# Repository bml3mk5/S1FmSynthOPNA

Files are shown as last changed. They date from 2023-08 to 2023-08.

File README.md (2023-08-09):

# FM音源カード for 日立 MB-S1 (OPNA (YM2608) バージョン)

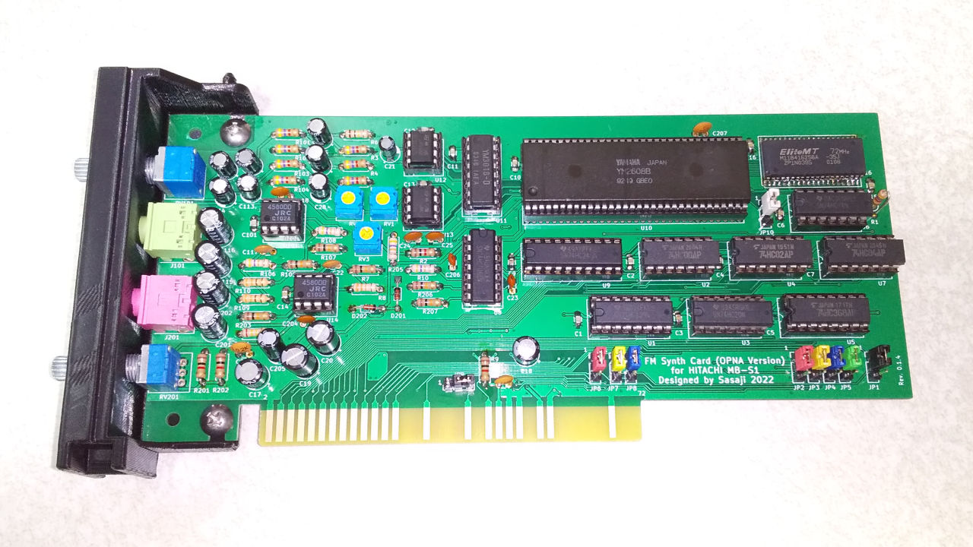
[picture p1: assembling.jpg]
Example of an assembling


## フォルダ構成

    BackCover/ ..................... 背面カバーの3Dモデル
    Board/ ......................... 基板設計(KiCAD 6.0)

-----
# FM Synthesis Card for HITACHI MB-S1 (OPNA (YM2608) Version)

## Folders:

    BackCover/ ..................... 3D models of the back cover
    Board/ ......................... The circuit board design (KiCAD 6.0)

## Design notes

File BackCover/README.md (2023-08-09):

# 背面カバーの3Dモデル

## ファイル構成

    S1BackSize_OPNA.FCStd .......... 本体の3Dデザイン(FreeCAD 0.2)
    S1BackSize_OPNA-Body.stl ....... 本体の3Dモデル
    S1BackSize_OPNA_Sp.FCStd ....... サポート部品の3Dデザイン(FreeCAD 0.2)
    S1BackSize_OPNA_Sp-Body001.stl . サポート部品の3Dモデル
    MegaZero2.0/ ................... Anycube MegaZero2.0用3Dデータ

-----
# 3D models of the back cover

## Files:

    S1BackSize_OPNA.FCStd .......... The 3D design of the main parts (FreeCAD 0.2)
    S1BackSize_OPNA-Body.stl ....... The 3D model of the main parts
    S1BackSize_OPNA_Sp.FCStd ....... The 3D design of the support parts for a 3D printer (FreeCAD 0.2)
    S1BackSize_OPNA_Sp-Body001.stl . The 3D model of the support parts for a 3D printer
    MegaZero2.0/ ................... The 3D data for Anycube MegaZero2.0

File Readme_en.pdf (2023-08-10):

## FM Synthesis Card （OPNA Version） for HITACHI MB-S1

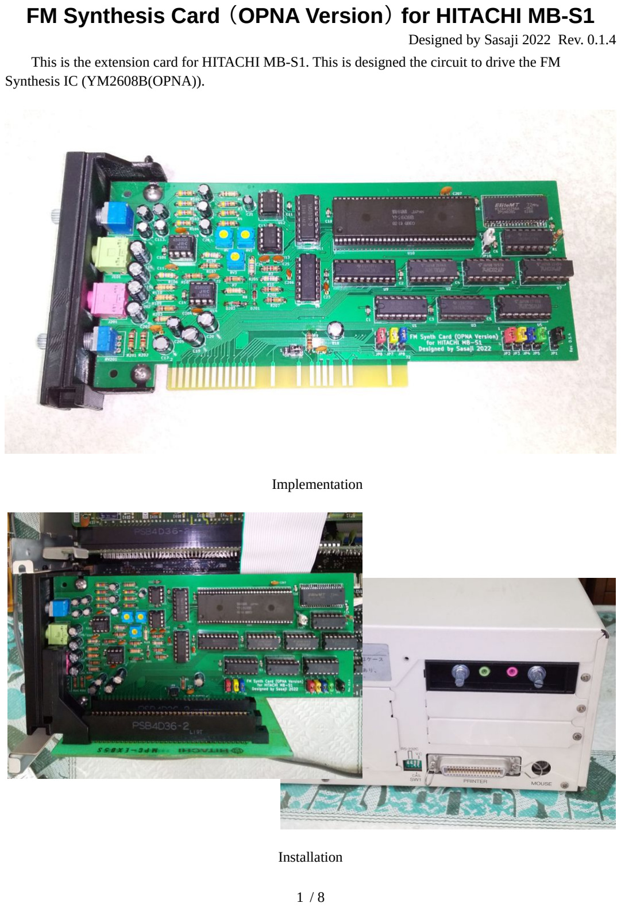
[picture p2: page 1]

Designed by Sasaji 2022 Rev. 0.1.4 This is the extension card for HITACHI MB-S1. This is designed the circuit to drive the FM Synthesis IC (YM2608B(OPNA)).

Implementation

Installation

## I/OPorts

The I/O ports are decided by Jumper setting. See detail Setting Jumper section.
| Jumper 1-2 | Jumper 2-3
YM2608B FM1ch~3ch, SSG, Rhythm | Address | $FFE7 | $FF1F
| Data | $FFE6 | $FF1E
YM2608B FM4ch~6ch, ADPCM | Address | $FFEF | $FF17
| Data | $FFEE | $FF16

## Setting Jumper

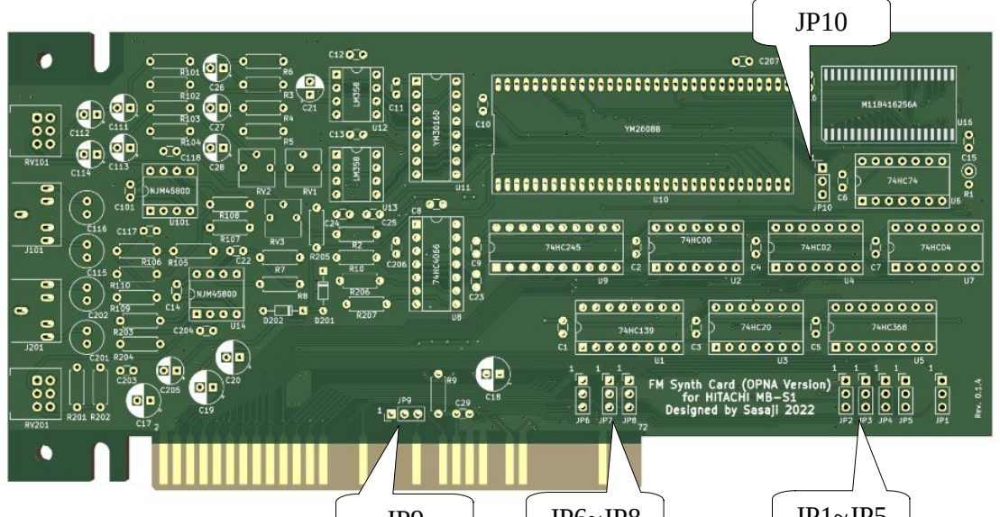
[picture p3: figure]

I/O Addresses of FM Synth (JP1～JP8)
- Pin number are #1,#2 and #3 from the top.
| JP1～JP6 | JP7, JP8 (*3)
I/O addresses Also use I/O addresses at $FF1E and $FF1F (*1) $FF16 and $FF17 to control FM4～6ch | Short 2-3 Short 2-3 | Short 2-3 Short 1-2
I/O addresses Also use I/O addresses at $FFE6 and $FFE7 (*2) $FFEE and $FFEF to control FM4～6ch | Short 1-2 Short 1-2 | Short 2-3 Short 1-2

(*1) Don’t use on B mode of MB-S1/30 and 40 because duplicate addresses of the FD interface. (*2) Select this if you use as Extended PSG.
(*3) The jumpers JP7 and JP8 must be at the same shorting position.
JP9 | JP6~JP8 | JP1~JP5

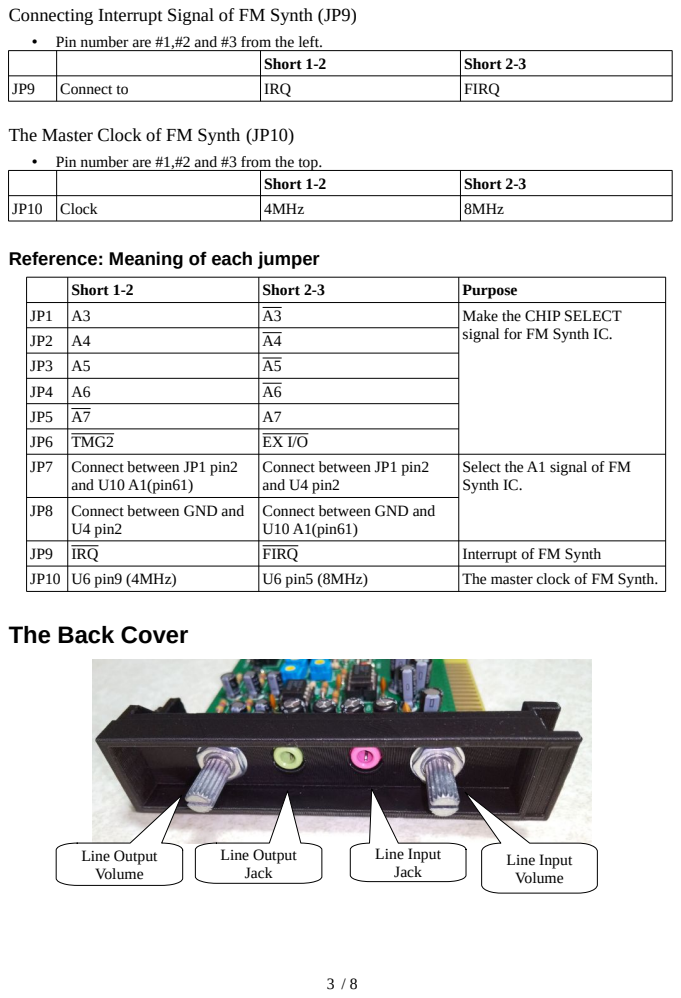
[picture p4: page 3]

Connecting Interrupt Signal of FM Synth (JP9)
• Pin number are #1,#2 and #3 from the left.

Short 1-2 | Short 2-3

JP9 | Connect to | IRQ | FIRQ

The Master Clock of FM Synth (JP10)
• Pin number are #1,#2 and #3 from the top.

JP10 | Clock | 4MHz | 8MHz

Reference: Meaning of each jumper

Short 1-2 | Short 2-3 | Purpose
JP1 | A3 | A3 | Make the CHIP SELECT
A4 | A4 | signal for FM Synth IC. JP2
JP3 | A5 | A5
JP4 | A6 | A6
JP5 | A7 | A7
JP6 | TMG2 | EX I/O
JP7 | Connect between JP1 pin2 and U10 A1(pin61) | Connect between JP1 pin2 and U4 pin2 | Select the A1 signal of FM Synth IC.

JP8 | Connect between GND and U4 pin2 | Connect between GND and U10 A1(pin61)

JP9 | IRQ | FIRQ | Interrupt of FM Synth
JP10 | U6 pin9 (4MHz) | U6 pin5 (8MHz) | The master clock of FM Synth.

## Setting Volume

## Balance of FM and SSG

Adjust RV1 - RV3 on the board. RV1: Left sound on FM
RV2: Right sound on FM
RV3:SSG

Usual position is 50 – 70%.

- When adjusted the RV1 - RV3, the volume of the built-in speaker and line out also changes.

## The volume of line output

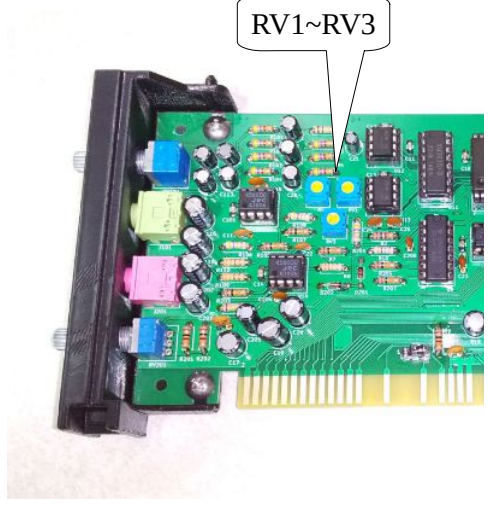
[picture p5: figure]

Adjust the volume appropriately according to the connected device.
- Small headphones (earphones): about 50%
- Line input of another device: about 20%
When using a large speaker, it is necessary to connect it via a drive circuit (amplifier).
- The PSG sound and BEEP on the main unit are not output from this terminal.

## The volume of line input

Adjust the volume appropriately according to the connected device.
- Line output of another device: about 20%
- Headphone output of another device: about 50%
When using a mic for PC, it is necessary to connect it via a drive circuit (amplifier).
- During recording, the audio from the main unit and line out are muted. And a little noise is recorded.

## Installing

Need the extension board (Riser card) to install to the main unit.
Parts Number：MPC-EX01S(MB-S1/10,20), MPC-EX03S, MPC-EX05S(MB-S1/30,40)

## Attention

This board cannot installs on LimeLight.
This board is a prototype. No consideration is given to noise generated during use and deterioration over time.

## Parts List

Parts number #1 to #99 are mandatory.
Parts number #101 to #199 are used on the line output circuit.
Parts number #201 to #299 are used on the line input circuit.
Parts Number | Parts Name | Qty. | Description
C1~C16, C101 | Ceramic Capacitor | 17 | 0.1uF, 10V～ | Power, Bypass
C22, C117, C118, C204 | Ceramic Capacitor | 4 | 100pF, 16V～ | Analog
C23, C206 | Ceramic Capacitor | 2 | 47pF, 10V～ | Analog
C24, C25, C207 | Ceramic Capacitor | 3 | 2200pF, 10V～ | Analog
C29, C203 | Ceramic Capacitor | 2 | 1000pF, 16V～ | Analog
C17, C18 | Electrolytic Capacitor | 2 | 47uF, 16V～ | Power, Bypass
C19, C20 | Electrolytic Capacitor | 2 | 100uF, 25V～ | Power, Bypass
C21 | Electrolytic Capacitor | 1 | 10uF, 16V～ | Analog
C26~C28, C111~C114 | Electrolytic Capacitor | 7 | 22uF, 16V～ | Analog
C205 | Electrolytic Capacitor | 1 | 22uF, 25V～ | Analog
C115, C116, C201, C202 | Electrolytic Capacitor (No polarity) | 4 | 22uF, 16V～ | Analog
R1 | Carbon Registor | 1 | 4.7KΩ, 1/4W～ | Digital, Pullup
R2, R9, R201, R202 | Carbon Registor | 4 | 1KΩ, 1/4W～ | Analog
R3~R5, R101~R104 | Carbon Registor | 7 | 4.7KΩ, 1/4W～ | Analog
R6 | Carbon Registor | 1 | 100KΩ, 1/4W～ | Analog
R7, R105, R107, R203, R206, R207 | Carbon Registor | 6 | 10KΩ, 1/4W～ | Analog
R8 | Carbon Registor | 1 | 33KΩ, 1/4W～ | Analog
R10, R106, R108, R205 | Carbon Registor | 4 | 47KΩ, 1/4W～ | Analog
R109, R110 | Carbon Registor | 2 | 330Ω, 1/4W～ | Analog
R204 | Carbon Registor | 1 | 240KΩ, 1/4W～ | Analog

RV1~RV3 | Potentiometer | 3 | 10KΩ (Tokyo Cosmos GF063P etc.) | Analog
RV101 | Potentiometer | 1 | 10KΩ, 2 Interlocking (Alps RK079 etc.) | Analog
RV201 | Potentiometer | 1 | 10KΩ, 1 or 2 Interlocking (Alps RK079 etc.) | Analog
D201, D202 | Diode | 2 | 1N4148 | Analog
U1 | CMOS Logic IC | 1 | 74HC139, DIP16 | Digital
U2 | CMOS Logic IC | 1 | 74HC00, DIP14 | Digital
U3 | CMOS Logic IC | 1 | 74HC20, DIP14 | Digital
U4 | CMOS Logic IC | 1 | 74HC02, DIP14 | Digital
U5 | CMOS Logic IC | 1 | 74HC368, DIP16 | Digital
U6 | CMOS Logic IC | 1 | 74HC74, DIP14 | Digital
U7 | CMOS Logic IC | 1 | 74HC04, DIP14 | Digital
U8 | CMOS Logic IC | 1 | 74HC4066, DIP14 | Digital
U9 | CMOS Logic IC | 1 | 74HC245, DIP20 | Digital
U10 | FM Synth IC | 1 | YM2608B, shrink DIP64 | Digital and Analog
U11 | DAC | 1 | YM3016D, DIP16 | Analog
U12, U13 | Opamp | 2 | LM358, DIP8 (+5V) | Analog
U14, U101 | Opamp | 2 | NJM4580DD, DIP8 (±12V) | Analog
U16 | DRAM | 1 | M11B416256A, SOIC40 | Digital
J101, J201 | Audio Jack | 2 | Stereo (PJ-317) | Analog
JP1~JP10 | Jumper | 10 | Pin Header 3pin x1 2.54mm pitch straight
| Jumper pin | 10 | To short pin headers.

Options

Parts Number | Parts Name | Qty. | Description
| IC Socket | 4 | DIP8
| IC Socket | 6 | DIP14
| IC Socket | 3 | DIP16
| IC Socket | 1 | DIP20
| IC Socket | 1 | Shrink DIP64

## Attention to build the board

Secure the back cover and board with two truss pin screws (B type, grooved) M3.5 x 8mm.
The back cover is fragile, so be careful and do not use too much force when tightening the screws.

## When omitting the line output circuit

No need for #100 series parts.

## When omitting the line input circuit

No need for #200 series parts.
Connect pin2 and pin3 of U14 to pin4 (GND).
U8 (74HC4066) can be omitted. If omitted:
- Connect pin3 and pin4 on U8.
- Also need not R10.

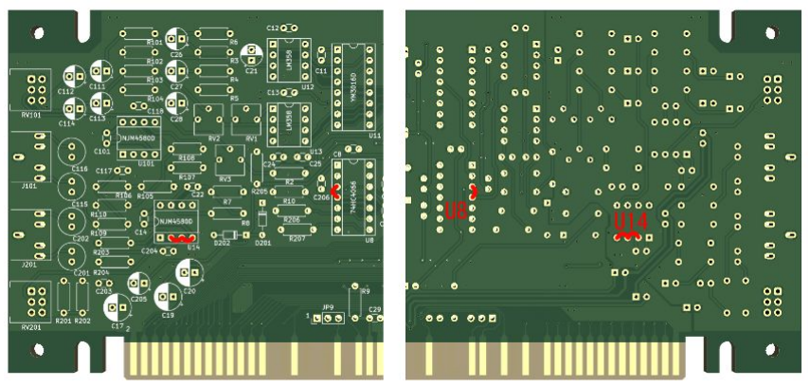
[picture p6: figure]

Treat either the front or the back on the board.

## No warranty

We are not responsible for any damage caused by this card. You use this card at your own risk.

## Web

This document and CAD data are opened on the web. http://s-sasaji.ddo.jp/bml3mk5/s1exmemfm.htm#opna

Sasaji (sasaji@s-sasaji.ddo.jp) http://s-sasaji.ddo.jp/bml3mk5/
(Twitter: https://twitter.com/bml3mk5)

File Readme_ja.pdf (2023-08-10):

# FM 音源カード（OPNA バージョン） for 日立 MB-S1

### Designed by Sasaji 2022 Rev. 0.1.4

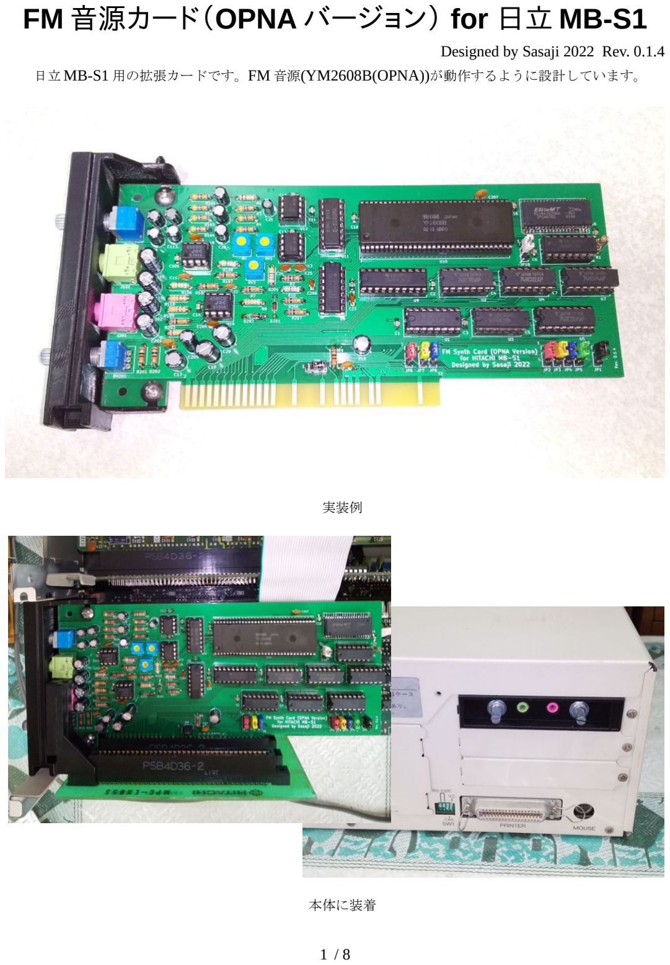
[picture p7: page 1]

日立 MB-S1 用の拡張カードです。FM 音源(YM2608B(OPNA))が動作するように設計しています。

実装例

本体に装着

# I/O ポート

YM2608B FM1ch~3ch, SSG, Rhythm | アドレス指定 | $FFE7 | $FF1F

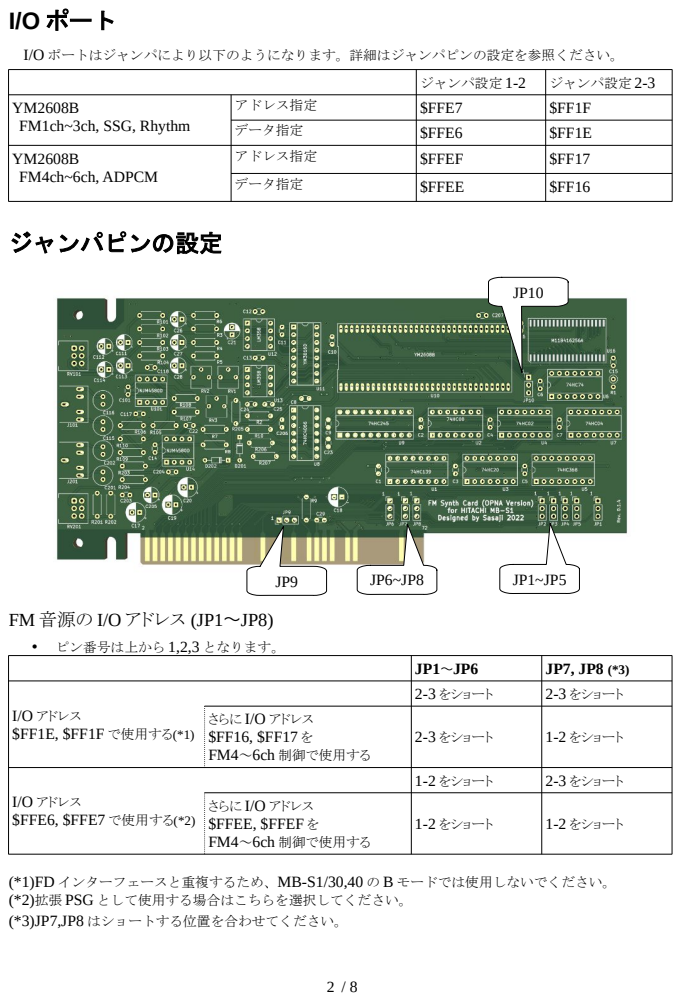
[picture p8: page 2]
I/O ポートはジャンパにより以下のようになります。詳細はジャンパピンの設定を参照ください。; ジャンパピンの設定; • ピン番号は上から 1,2,3 となります。

ジャンパ設定 1-2 | ジャンパ設定 2-3

データ指定 | $FFE6 | $FF1E

YM2608B FM4ch~6ch, ADPCM | アドレス指定 | $FFEF | $FF17

データ指定 | $FFEE | $FF16

FM 音源の I/O アドレス (JP1～JP8)

I/O アドレス さらに I/O アドレス $FF1E, $FF1F で使用する(*1) $FF16, $FF17 を FM4～6ch 制御で使用する | 2-3 をショート | 2-3 をショート 1-2 をショート

I/O アドレス さらに I/O アドレス $FFE6, $FFE7 で使用する(*2) $FFEE, $FFEF を FM4～6ch 制御で使用する | 1-2 をショート | 2-3 をショート 1-2 をショート

(*1)FD インターフェースと重複するため、MB-S1/30,40 の B モードでは使用しないでください。
(*2)拡張 PSG として使用する場合はこちらを選択してください。
(*3)JP7,JP8 はショートする位置を合わせてください。

## FM 音源の割り込み信号接続先(JP9)

JP9 | 割り込み信号接続先 | IRQ | FIRQ

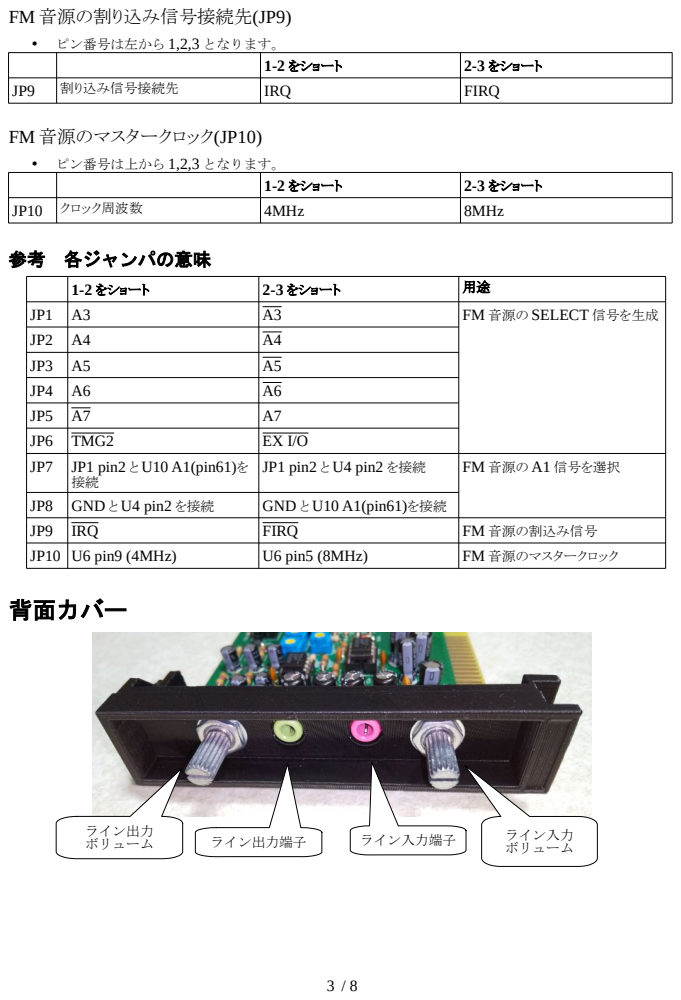
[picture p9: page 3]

1-2 をショート | 2-3 をショート

JP10 | クロック周波数 | 4MHz | 8MHz

1-2 をショート | 2-3 をショート | 用途
JP1 | A3 | A3 | FM 音源の SELECT 信号を生成
JP2 | A4 | A4
JP3 | A5 | A5
JP4 | A6 | A6
JP5 | A7 | A7
JP6 | TMG2 | EX I/O
JP7 | JP1 pin2 と U10 A1(pin61)を 接続 | JP1 pin2 と U4 pin2 を接続 | FM 音源の A1 信号を選択

JP8 | GND と U4 pin2 を接続 | GND と U10 A1(pin61)を接続
JP9 | IRQ | FIRQ | FM 音源の割込み信号
JP10 | U6 pin9 (4MHz) | U6 pin5 (8MHz) | FM 音源のマスタークロック

# 音量調整


## FM 部と SSG 部のバランス

基板上にある RV1~RV3 で調整します。

### RV1: FM 部左音声 RV2: FM 部右音声 RV3:SSG 部

50～75%ぐらいが目安。

- RV1~RV3 を調整すると内蔵スピーカ及びライン出力の音 量も変化します。

## ライン出力のボリューム

接続する機器に応じて、適宜ボリュームを調整してください。
- 小型のヘッドホン（イヤホン）を接続する場合、だいたい 50%ぐらい。
- 別機器のライン入力に接続する場合、だいたい 20%ぐらい。

大型スピーカなどはドライブ回路（アンプ）を介して接続する必要があります。

- ライン出力からは FM 音源の音声のみ出力されます。本体の PSG 音源や BEEP 音は出力されません。

## ライン入力のボリューム

接続する機器に応じて、適宜ボリュームを調整してください。
- 別機器のライン出力と接続する場合、だいたい 20%ぐらい。
- 別機器のヘッドホン出力と接続する場合、だいたい 50%ぐらい。

PC 用のマイクはドライブ回路（アンプ）を介して接続する必要があります。

- 録音中は本体及びライン出力の音声はミュートされます。また若干のノイズがはいります。

# 本体への装着

装着には拡張ボード（ライザーカード）が必要です。

### 品番：MPC-EX01S(MB-S1/10,20 用), MPC-EX03S, MPC-EX05S(MB-S1/30,40 用)など

# 使用上の注意

- 来夢来人では背面カバーが干渉するため使用できません。
- この基板は試作品です。使用中に発生するノイズや経年劣化などに対しての考慮は全くしていません ので予めご了承ください。

# 部品表

番号 1~99 は必須部品。

番号 101~199 はライン出力回路で使用する部品。

番号 201~299 はライン入力回路で使用する部品。

番号 | 部品名 | 数量 | 値など | 用途
C1~C16, C101 | セラミックコンデンサ | 17 | 0.1uF, 10V～ | 電源・パスコン
C22, C117, C118, C204 | セラミックコンデンサ | 4 | 100pF, 16V～ | アナログ音声
C23, C206 | セラミックコンデンサ | 2 | 47pF, 10V～ | アナログ音声
C24, C25, C207 | セラミックコンデンサ | 3 | 2200pF, 10V～ | アナログ音声
C29, C203 | セラミックコンデンサ | 2 | 1000pF, 16V～ | アナログ音声
C17, C18 | 電解コンデンサ | 2 | 47uF, 16V～ | 電源・パスコン
C19, C20 | 電解コンデンサ | 2 | 100uF, 25V～ | 電源・パスコン
C21 | 電解コンデンサ | 1 | 10uF, 16V～ | アナログ音声
C26~C28, C111~C114 | 電解コンデンサ | 7 | 22uF, 16V～ | アナログ音声
C205 | 電解コンデンサ | 1 | 22uF, 25V～ | アナログ音声
C115, C116, C201, C202 | 無極性電解コンデンサ | 4 | 22uF, 16V～ | アナログ音声
R1 | カーボン抵抗 | 1 | 4.7KΩ, 1/4W～ | デジタル・プル アップ
R2, R9, R201, R202 | カーボン抵抗 | 4 | 1KΩ, 1/4W～ | アナログ音声
R3~R5, R101~R104 | カーボン抵抗 | 7 | 4.7KΩ, 1/4W～ | アナログ音声
R6 | カーボン抵抗 | 1 | 100KΩ, 1/4W～ | アナログ音声
R7, R105, R107, R203, R206, R207 | カーボン抵抗 | 6 | 10KΩ, 1/4W～ | アナログ音声
R8 | カーボン抵抗 | 1 | 33KΩ, 1/4W～ | アナログ音声
R10, R106, R108, R205 | カーボン抵抗 | 4 | 47KΩ, 1/4W～ | アナログ音声
R109, R110 | カーボン抵抗 | 2 | 330Ω, 1/4W～ | アナログ音声
R204 | カーボン抵抗 | 1 | 240KΩ, 1/4W～ | アナログ音声

RV1~RV3 | 半固定抵抗 | 3 | 10KΩ (東京コスモス GF063P など) | アナログ音声
RV101 | 可変抵抗 | 1 | 10KΩ, 2 連 (Alps RK079 など) | アナログ音声
RV201 | 可変抵抗 | 1 | 10KΩ, 1 連または 2 連 (Alps RK079 など) | アナログ音声
D201, D202 | ダイオード | 2 | 1N4148 など小信号のもの | アナログ音声
U1 | CMOS ロジック IC | 1 | 74HC139, DIP16 ピン | デジタル
U2 | CMOS ロジック IC | 1 | 74HC00, DIP14 ピン | デジタル
U3 | CMOS ロジック IC | 1 | 74HC20, DIP14 ピン | デジタル
U4 | CMOS ロジック IC | 1 | 74HC02, DIP14 ピン | デジタル
U5 | CMOS ロジック IC | 1 | 74HC368, DIP16 ピン | デジタル
U6 | CMOS ロジック IC | 1 | 74HC74, DIP14 ピン | デジタル
U7 | CMOS ロジック IC | 1 | 74HC04, DIP14 ピン | デジタル
U8 | CMOS ロジック IC | 1 | 74HC4066, DIP14 ピン | デジタル
U9 | CMOS ロジック IC | 1 | 74HC245, DIP20 ピン | デジタル
U10 | FM 音源 | 1 | YM2608B, シュリンク DIP64 ピン | デジタル・アナロ グ
U11 | DAC | 1 | YM3016D, DIP16 ピン | アナログ音声
U12, U13 | オペアンプ | 2 | LM358, DIP8 ピン (片電源 +5V) | アナログ音声
U14, U101 | オペアンプ | 2 | NJM4580DD, DIP8 ピン (±12V 以上のもの) | アナログ音声
U16 | DRAM | 1 | M11B416256A, SOIC40 ピン | デジタル
J101, J201 | オーディオジャック | 2 | ステレオ (PJ-317) | アナログ音声
JP1~JP10 | ジャンパ | 10 | ピンヘッダ 3 ピン x1 列 2.54mm ピッ チ ストレート
| ジャンパピン | 10 | 上記ジャンパをショートさせるため

## オプション

番号 | 部品名 | 数量 | 値など | 用途
| IC ソケット | 4 | DIP8 ピン
| IC ソケット | 6 | DIP14 ピン
| IC ソケット | 3 | DIP16 ピン
| IC ソケット | 1 | DIP20 ピン
| IC ソケット | 1 | シュリンク DIP64 ピン

# 組立て時の注意

背面カバーと基板は、トラスタッピンネジ（B 型、溝つき） M3.5 x 8mm 2 本で固定します。 背面カバーはもろいため、ネジを止める際はゆっくりあまり力を入れないようにしてください。

# ライン出力回路を省略する場合

100 番台の部品は不要です。

# ライン入力回路を省略する場合

200 番台の部品は不要です。

### U14 の pin2,pin3 を pin4(GND)に接続してください。

U8 (74HC4066)は省略できます。省略する場合：
- U8 の pin3 と pin4 を接続してください。
- R10 も不要です。


表面か裏面どちらかに処置してください。

# 免責事項

この基板によって発生したいかなる損害についても当方は一切責任を負いません。 この基板を使用するにあたってはすべて自己責任で行ってください。

# Web ページ

この資料や CAD データなどを置いています。

### http://s-sasaji.ddo.jp/bml3mk5/s1exmemfm.htm#opna

連絡先：

### Sasaji (sasaji@s-sasaji.ddo.jp) http://s-sasaji.ddo.jp/bml3mk5/ (Twitter: https://twitter.com/bml3mk5)

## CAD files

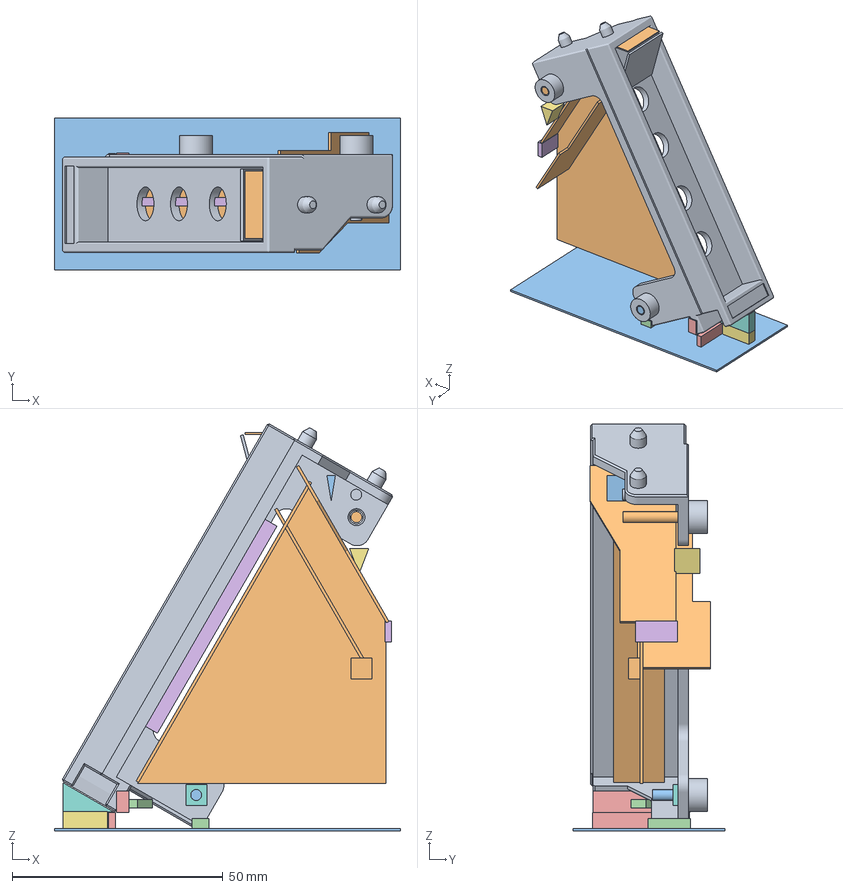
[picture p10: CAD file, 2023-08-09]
BackCover/MegaZero2.0/S1BackSide_OPNA-Sp6-4.3mf
82.0 x 36.0 x 96.5 mm
S1BackSide_OPNA-Sp6.3mf
S1BackSide_OPNA-Sp6.3mf(1)
S1BackSide_OPNA-Sp6.3mf(2)
S1BackSide_OPNA-Sp6.3mf(4)
S1BackSide_OPNA-Sp6.3mf(5)
S1BackSide_OPNA-Sp6.3mf(6)
S1BackSide_OPNA-Sp6.3mf(7)
Square5-Body.stl
Square5-Body.stl(2)
cylinder_r1_10-Body.stl
cylinder_r1_10-Body.stl(1)
Square5-Body.stl(1)
Square5-Body.stl(3)
Square5-Body.stl(4)
Square5-Body.stl(5)
Triangle_b5-Body.stl
cylinder_r1_10-Body.stl(2)
Square5-Body.stl(6)
S1BackSide_OPNA-Sp6.3mf(3)

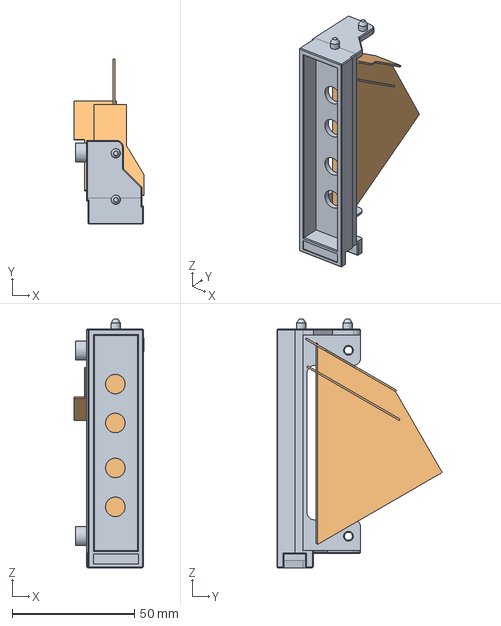
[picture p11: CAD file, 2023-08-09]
BackCover/S1BackSide_OPNA_Sp.FCStd
28.6 x 67.7 x 101.8 mm

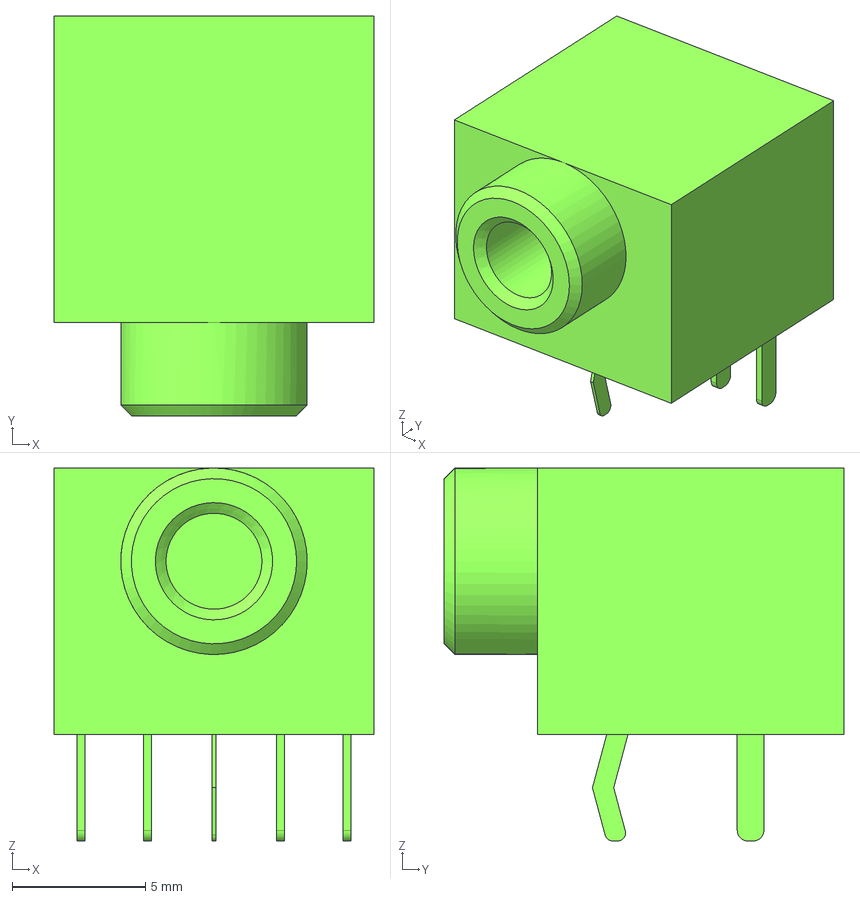
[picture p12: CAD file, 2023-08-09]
Board/PJ317G-Body.step
12.0 x 15.0 x 14.0 mm

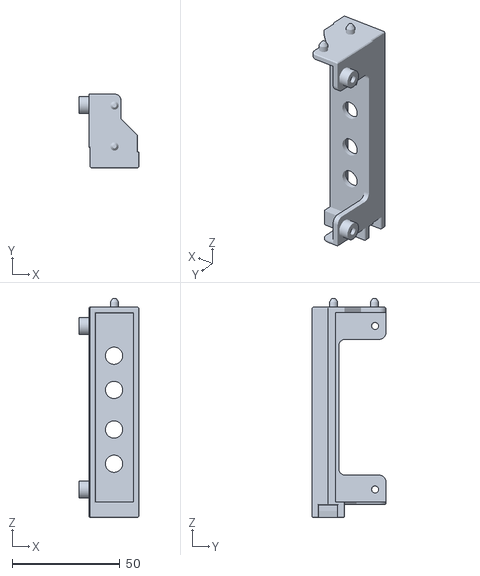
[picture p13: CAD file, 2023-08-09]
BackCover/S1BackSide_OPNA-Body.stl
27.7 x 34.3 x 101.8

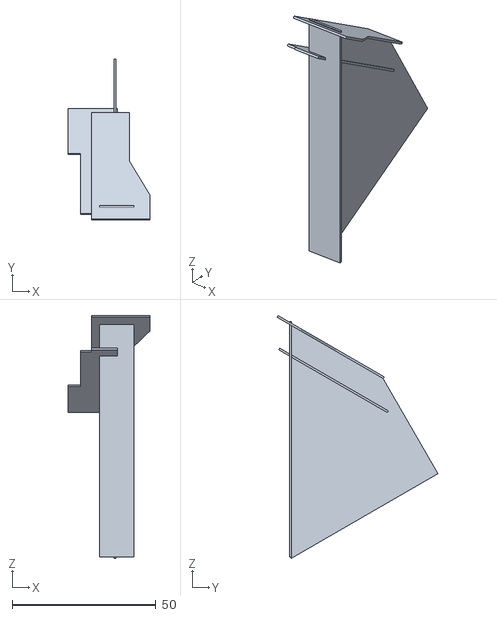
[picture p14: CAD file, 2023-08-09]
BackCover/S1BackSide_OPNA_Sp-Body001.stl
28.6 x 56.0 x 84.5

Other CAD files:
Board/PJ317P-Body.step
BackCover/S1BackSide_OPNA.FCStd

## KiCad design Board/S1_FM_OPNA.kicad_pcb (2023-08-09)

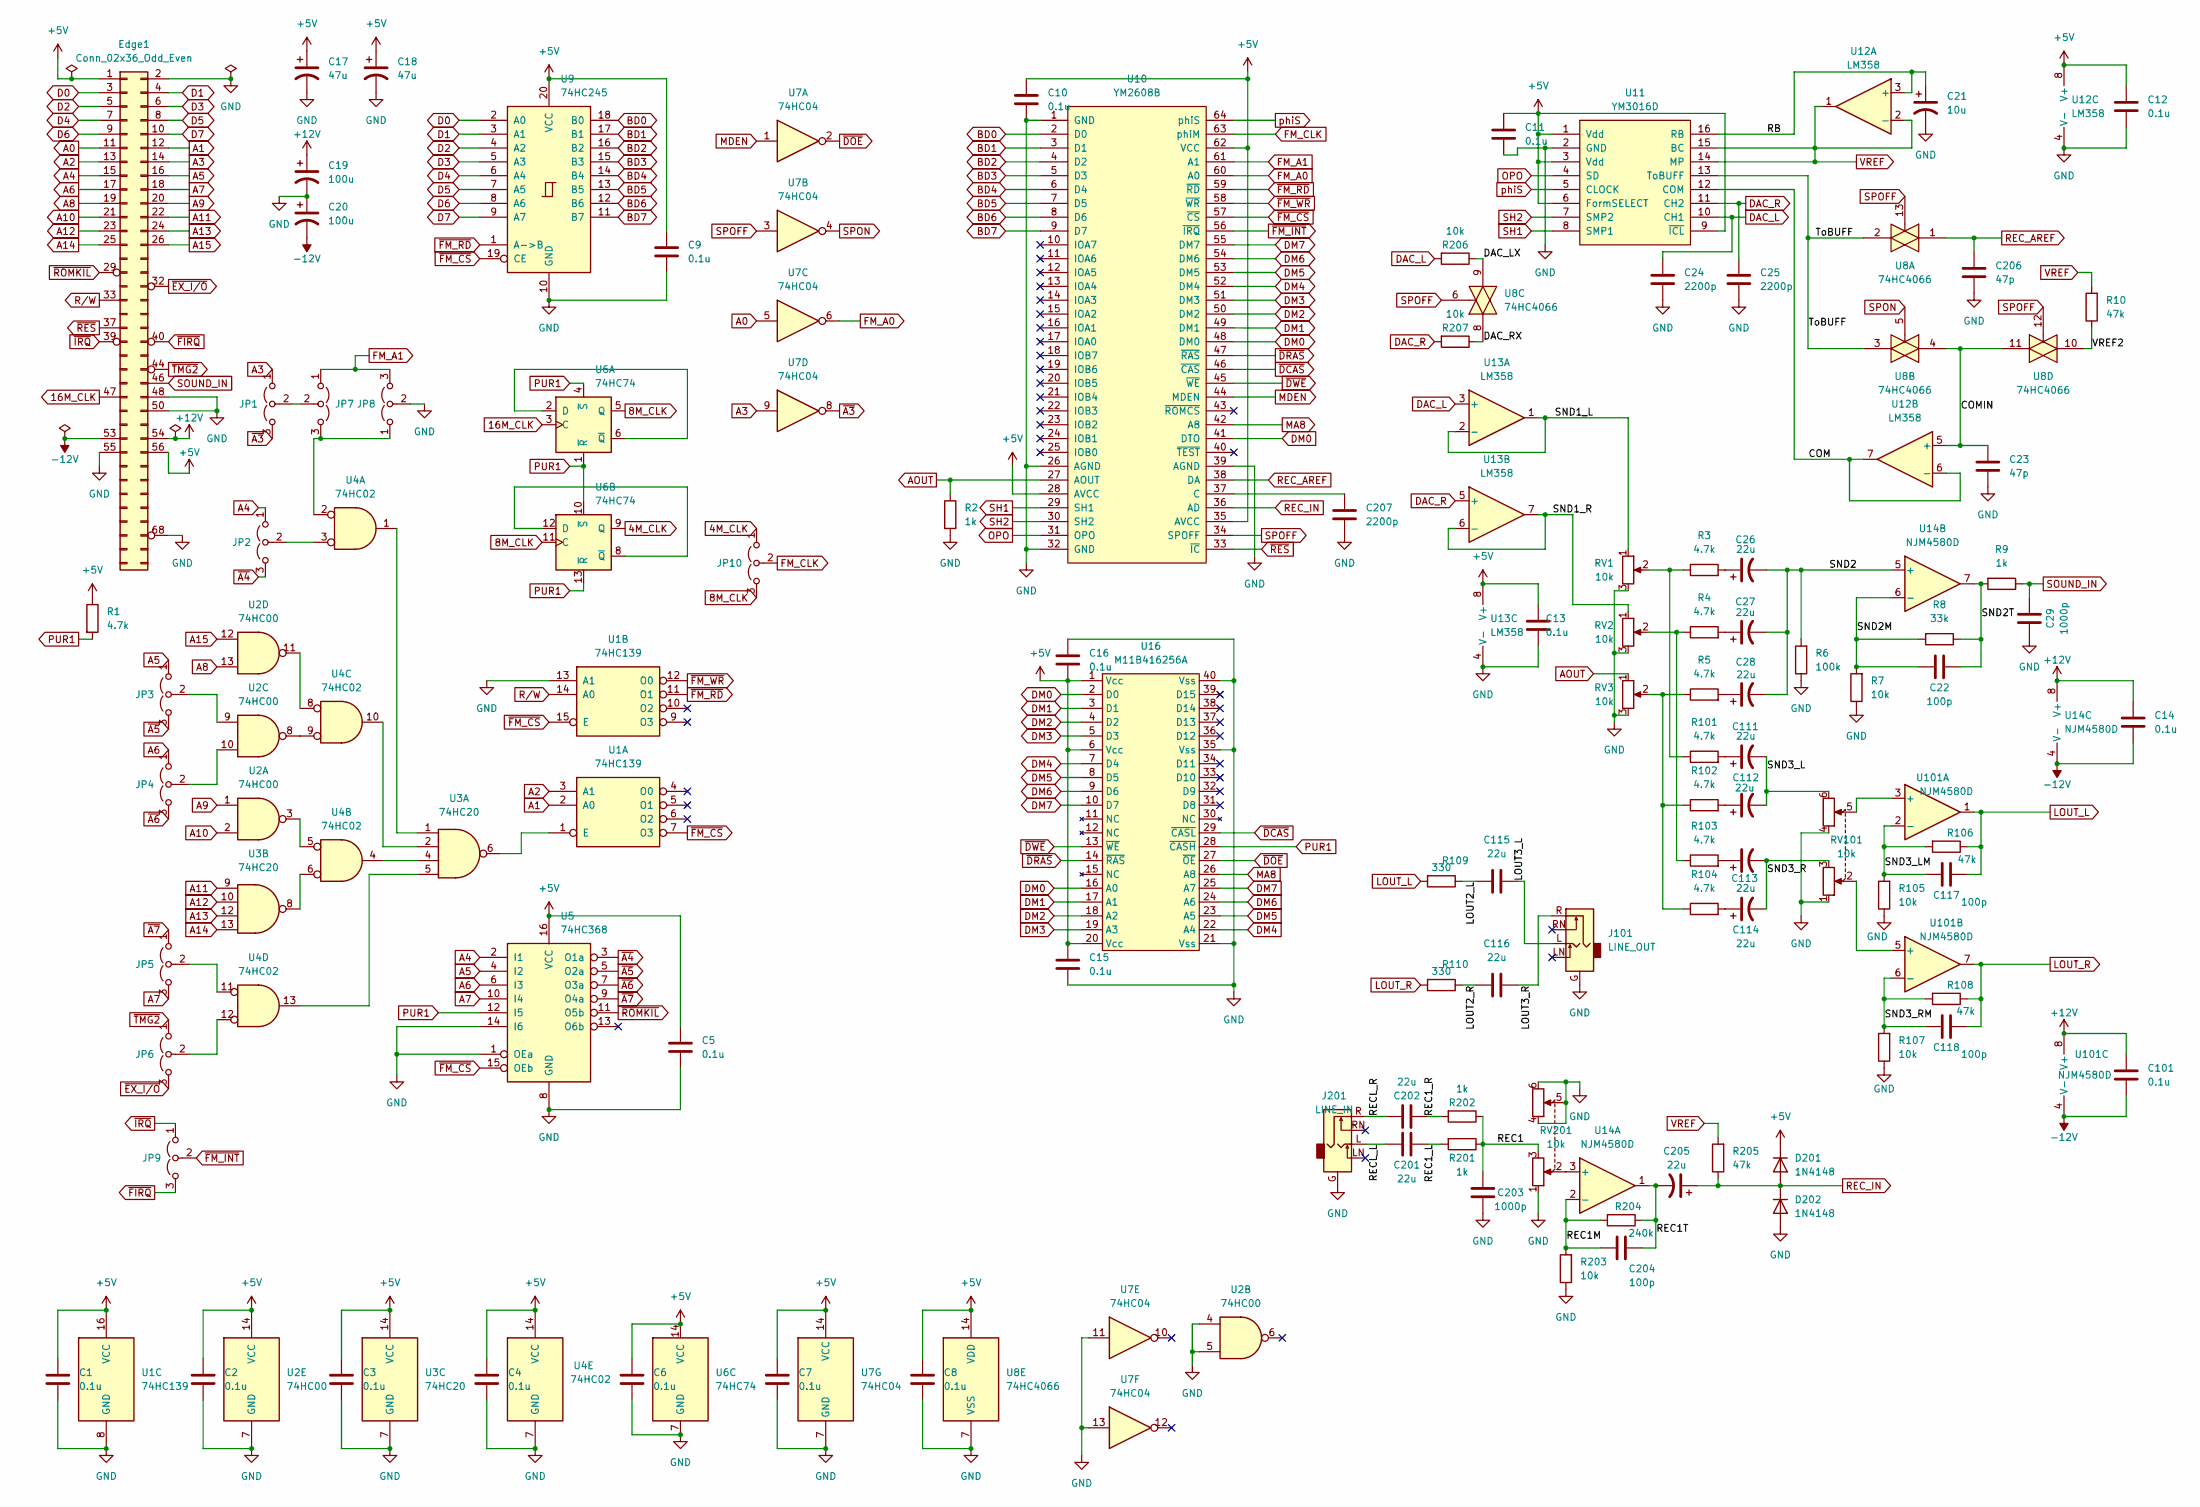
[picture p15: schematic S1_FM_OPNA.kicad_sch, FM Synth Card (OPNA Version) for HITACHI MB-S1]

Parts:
C1, C2, C3, C4, C5, C6, C7, C8, C9, C10, C11, C12, C13, C14, C15, C16, C101: 0.1u; C_Disc_D3.0mm_W1.6mm_P2.50mm
C17, C18: 47u; CP_Radial_D6.3mm_P2.50mm
C19, C20: 100u; CP_Radial_D6.3mm_P2.50mm
C21: 10u; CP_Radial_D5.0mm_P2.50mm
C22, C117, C118, C204: 100p; C_Disc_D3.0mm_W1.6mm_P2.50mm
C23, C206: 47p; C_Disc_D3.0mm_W1.6mm_P2.50mm
C24, C25, C207: 2200p; C_Disc_D3.0mm_W1.6mm_P2.50mm
C26, C27, C28, C111, C112, C113, C114, C205: 22u; CP_Radial_D5.0mm_P2.50mm
C29, C203: 1000p; C_Disc_D3.0mm_W1.6mm_P2.50mm
C115, C116, C201, C202: 22u; C_Radial_D6.3mm_H5.0mm_P2.50mm
D201, D202: 1N4148; D_DO-34_SOD68_P7.62mm_Horizontal
Edge1: Conn_02x36_Odd_Even; CardEdge72
J101: LINE_OUT; Jack_3.5mm_CUI_PJ317_Horizontal_X
J201: LINE_IN; Jack_3.5mm_CUI_PJ317_Horizontal_X
JP1, JP2, JP3, JP4, JP5, JP6, JP7, JP8, JP9, JP10: Jumper_3_Open; PinHeader_1x03_P2.54mm_Vertical
R1: 4.7k; R_Axial_DIN0207_L6.3mm_D2.5mm_P2.54mm_Vertical
R2, R9, R201, R202: 1k; R_Axial_DIN0207_L6.3mm_D2.5mm_P7.62mm_Horizontal
R3, R4, R5, R101, R102, R103, R104: 4.7k; R_Axial_DIN0207_L6.3mm_D2.5mm_P7.62mm_Horizontal
R6: 100k; R_Axial_DIN0207_L6.3mm_D2.5mm_P7.62mm_Horizontal
R7, R105, R107, R203, R206, R207: 10k; R_Axial_DIN0207_L6.3mm_D2.5mm_P7.62mm_Horizontal
R8: 33k; R_Axial_DIN0207_L6.3mm_D2.5mm_P7.62mm_Horizontal
R10, R106, R108, R205: 47k; R_Axial_DIN0207_L6.3mm_D2.5mm_P7.62mm_Horizontal
R109, R110: 330; R_Axial_DIN0207_L6.3mm_D2.5mm_P7.62mm_Horizontal
R204: 240k; R_Axial_DIN0207_L6.3mm_D2.5mm_P7.62mm_Horizontal
RV1, RV2, RV3: 10k; Potentiometer_Vishay_T73YP_Vertical
RV101, RV201: 10k; Potentiometer_Alps_RK097_Dual_Horizontal_X
U1: 74HC139; DIP-16_W7.62mm_Socket
U2: 74HC00; DIP-14_W7.62mm_Socket
U3: 74HC20; DIP-14_W7.62mm_Socket
U4: 74HC02; DIP-14_W7.62mm_Socket
U5: 74HC368; DIP-16_W7.62mm_Socket
U6: 74HC74; DIP-14_W7.62mm_Socket
U7: 74HC04; DIP-14_W7.62mm_Socket
U8: 74HC4066; DIP-14_W7.62mm_Socket
U9: 74HC245; DIP-20_W7.62mm_Socket
U10: YM2608B; SDIP-64
U11: YM3016D; DIP-16_W7.62mm_Socket
U12, U13: LM358; DIP-8_W7.62mm_Socket
U14, U101: NJM4580D; DIP-8_W7.62mm_Socket
U16: M11B416256A; SOIC-40

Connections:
4M_CLK: JP10.1 (A), U6.9 (Q)
8M_CLK: JP10.3 (B), U6.5 (Q), U6.11 (C)
16M_CLK: Edge1.47 (16M_CLK), U6.3 (C)
+5V: C1.1, C2.1, C3.1, C4.1, C5.1, C6.1, C7.1, C8.1, C9.1, C10.1, C11.1, C12.1, C13.1, C15.1, C16.2, C17.1, C18.1, D201.1 (K), Edge1.1 (Vcc), Edge1.56 (Vcc), R1.1, U1.16 (VCC), U2.14 (VCC), U3.14 (VCC), U4.14 (VCC), U5.16 (VCC), U6.14 (VCC), U7.14 (VCC), U8.14 (VDD), U9.20 (VCC), U10.28 (AVCC), U10.35 (AVCC), U10.62 (VCC), U11.1 (Vdd), U11.3 (Vdd), U11.6 (FormSELECT), U11.9 (~ICL), U12.8 (V+), U13.8 (V+), U16.1 (Vcc), U16.6 (Vcc), U16.20 (Vcc)
+12V: C14.1, C19.1, C101.1, Edge1.54 (+12V), U14.8 (V+), U101.8 (V+)
-12V: C14.2, C20.2, C101.2, Edge1.53 (-12V), U14.4 (V-), U101.4 (V-)
/COM: U11.12 (COM), U12.6 (-), U12.7
/COMIN: C23.1, U8.4, U8.11, U12.5 (+)
/DAC_LX: R206.1, U8.9
/DAC_RX: R207.1, U8.8
/LOUT2_L: C115.1, R109.1
/LOUT2_R: C116.1, R110.1
/LOUT3_L: C115.2, J101.L
/LOUT3_R: C116.2, J101.R
/RB: C21.1, U11.16 (RB), U12.3 (+)
/REC1: C203.1, R201.1, R202.1, RV201.3
/REC1M: C204.2, R203.2, R204.2, U14.2 (-)
/REC1T: C204.1, C205.2, R204.1, U14.1
/REC1_L: C201.2, R201.2
/REC1_R: C202.2, R202.2
/RECL_L: C201.1, J201.L
/RECL_R: C202.1, J201.R
/SND1_L: RV1.1, U13.1, U13.2 (-)
/SND1_R: RV2.1, U13.6 (-), U13.7
/SND2: C26.2, C27.2, C28.2, R6.2, U14.5 (+)
/SND2M: C22.2, R7.2, R8.2, U14.6 (-)
/SND2T: C22.1, R8.1, R9.2, U14.7
/SND3_L: C111.2, C112.2, RV101.6
/SND3_LM: C117.2, R105.2, R106.2, U101.2 (-)
/SND3_R: C113.2, C114.2, RV101.3
/SND3_RM: C118.2, R107.2, R108.2, U101.6 (-)
/ToBUFF: U8.2, U8.3, U11.13 (ToBUFF)
/VREF2: R10.1, U8.10
A0: Edge1.11 (A0), U7.5
A1: Edge1.12 (A1), U1.2 (A0)
A2: Edge1.13 (A2), U1.3 (A1)
A3: Edge1.14 (A3), JP1.1 (A), U7.9
A4: Edge1.15 (A4), JP2.1 (A), U5.2 (I1)
A5: Edge1.16 (A5), JP3.1 (A), U5.4 (I2)
A6: Edge1.17 (A6), JP4.1 (A), U5.6 (I3)
A7: Edge1.18 (A7), JP5.3 (B), U5.10 (I4)
A8: Edge1.19 (A8), U2.13
A9: Edge1.20 (A9), U2.1
A10: Edge1.21 (A10), U2.2
A11: Edge1.22 (A11), U3.9
A12: Edge1.23 (A12), U3.10
A13: Edge1.24 (A13), U3.12
A14: Edge1.25 (A14), U3.13
A15: Edge1.26 (A15), U2.12
AOUT: R2.1, RV3.1, U10.27 (AOUT)
BD0: U9.18 (B0), U10.2 (D0)
BD1: U9.17 (B1), U10.3 (D1)
BD2: U9.16 (B2), U10.4 (D2)
BD3: U9.15 (B3), U10.5 (D3)
BD4: U9.14 (B4), U10.6 (D4)
BD5: U9.13 (B5), U10.7 (D5)
BD6: U9.12 (B6), U10.8 (D6)
BD7: U9.11 (B7), U10.9 (D7)
D0: Edge1.3 (D0), U9.2 (A0)
D1: Edge1.4 (D1), U9.3 (A1)
D2: Edge1.5 (D2), U9.4 (A2)
D3: Edge1.6 (D3), U9.5 (A3)
D4: Edge1.7 (D4), U9.6 (A4)
D5: Edge1.8 (D5), U9.7 (A5)
D6: Edge1.9 (D6), U9.8 (A6)
D7: Edge1.10 (D7), U9.9 (A7)
DAC_L: C24.1, R206.2, U11.10 (CH1), U13.3 (+)
DAC_R: C25.1, R207.2, U11.11 (CH2), U13.5 (+)
DM0: U10.41 (DTO), U10.48 (DM0), U16.2 (D0), U16.16 (A0)
DM1: U10.49 (DM1), U16.3 (D1), U16.17 (A1)
DM2: U10.50 (DM2), U16.4 (D2), U16.18 (A2)
DM3: U10.51 (DM3), U16.5 (D3), U16.19 (A3)
DM4: U10.52 (DM4), U16.7 (D4), U16.22 (A4)
DM5: U10.53 (DM5), U16.8 (D5), U16.23 (A5)
DM6: U10.54 (DM6), U16.9 (D6), U16.24 (A6)
DM7: U10.55 (DM7), U16.10 (D7), U16.25 (A7)
FM_A0: U7.6, U10.60 (A0)
FM_A1: JP7.1 (A), JP8.3 (B), U10.61 (A1)
FM_CLK: JP10.2 (C), U10.63 (phiM)
GND: C1.2, C2.2, C3.2, C4.2, C5.2, C6.2, C7.2, C8.2, C9.2, C10.2, C11.2, C12.2, C13.2, C15.2, C16.1, C17.2, C18.2, C19.2, C20.1, C21.2, C23.2, C24.2, C25.2, C29.2, C203.2, C206.2, C207.2, D202.2 (A), Edge1.2 (GND), Edge1.48 (GND), Edge1.50 (GND), Edge1.55 (GND), Edge1.68 (~S1_IF_SEL), J101.G, J201.G, JP8.2 (C), R2.2, R6.1, R7.1, R105.1, R107.1, R203.1, RV1.3, RV2.3, RV3.3, RV101.1, RV101.4, RV201.1, RV201.4, RV201.5, RV201.6, U1.8 (GND), U1.13 (A1), U2.4, U2.5, U2.7 (GND), U3.7 (GND), U4.7 (GND), U5.1 (OEa), U5.8 (GND), U5.14 (I6), U6.7 (GND), U7.7 (GND), U7.11, U7.13, U8.7 (VSS), U9.10 (GND), U10.1 (GND), U10.26 (AGND), U10.32 (GND), U10.39 (AGND), U11.2 (GND), U12.4 (V-), U13.4 (V-), U16.21 (Vss), U16.35 (Vss), U16.40 (Vss)
LOUT_L: C117.1, R106.1, R109.2, U101.1
LOUT_R: C118.1, R108.1, R110.2, U101.7
MA8: U10.42 (A8), U16.26 (A8)
MDEN: U7.1, U10.44 (MDEN)
unnamed: C26.1, R3.2
unnamed: C27.1, R4.2
unnamed: C28.1, R5.2
unnamed: C111.1, R101.2
unnamed: C112.1, R102.2
unnamed: C113.1, R103.2
unnamed: C114.1, R104.2
unnamed: C207.1, U10.37 (C)
unnamed: JP1.2 (C), JP7.2 (C)
unnamed: JP2.2 (C), U4.3
unnamed: JP3.2 (C), U2.9
unnamed: JP4.2 (C), U2.10
unnamed: JP5.2 (C), U4.11
unnamed: JP6.2 (C), U4.12
unnamed: JP7.3 (B), JP8.1 (A), U4.2
unnamed: R3.1, R101.1, RV1.2
unnamed: R5.1, R102.1, R104.1, RV3.2
unnamed: R4.1, R103.1, RV2.2
unnamed: RV101.2, U101.5 (+)
unnamed: RV101.5, U101.3 (+)
unnamed: RV201.2, U14.3 (+)
unnamed: U1.1 (E), U3.6
unnamed: U2.3, U4.5
unnamed: U2.8, U4.9
unnamed: U2.11, U4.8
unnamed: U3.1, U4.1
unnamed: U3.2, U4.10
unnamed: U3.4, U4.4
unnamed: U3.5, U4.13
unnamed: U3.8, U4.6
unnamed: U6.2 (D), U6.6 (~Q)
unnamed: U6.8 (~Q), U6.12 (D)
OPO: U10.31 (OPO), U11.4 (SD)
PUR1: R1.2, U5.12 (I5), U6.1 (~R), U6.4 (~S), U6.10 (~S), U6.13 (~R), U16.28 (~CASH)
REC_AREF: C206.1, U8.1, U10.38 (DA)
REC_IN: C205.1, D201.2 (A), D202.1 (K), R205.1, U10.36 (AD)
R/W: Edge1.33 (R/W_OUT), U1.14 (A0)
SH1: U10.29 (SH1), U11.8 (SMP1)
SH2: U10.30 (SH2), U11.7 (SMP2)
SOUND_IN: C29.1, Edge1.46 (SOUND_IN), R9.1
SPOFF: U7.3, U8.6, U8.12, U8.13, U10.34 (SPOFF)
SPON: U7.4, U8.5
VREF: R10.2, R205.2, U11.14 (MP), U11.15 (BC), U12.1, U12.2 (-)
phiS: U10.64 (phiS), U11.5 (CLOCK)
~A3: JP1.3 (B), U7.8
~A4: JP2.3 (B), U5.3 (O1a)
~A5: JP3.3 (B), U5.5 (O2a)
~A6: JP4.3 (B), U5.7 (O3a)
~A7: JP5.1 (A), U5.9 (O4a)
~DCAS: U10.46 (~CAS), U16.29 (~CASL)
~DOE: U7.2, U16.27 (~OE)
~DRAS: U10.47 (~RAS), U16.14 (~RAS)
~DWE: U10.45 (~WE), U16.13 (~WE)
~EX_I/O: Edge1.32 (~EX_I/O), JP6.3 (B)
~FIRQ: Edge1.40 (~FIRQ), JP9.3 (B)
~FM_CS: U1.7 (O3), U1.15 (E), U5.15 (OEb), U9.19 (CE), U10.57 (~CS)
~FM_INT: JP9.2 (C), U10.56 (~IRQ)
~FM_RD: U1.11 (O1), U9.1 (A->B), U10.59 (~RD)
~FM_WR: U1.12 (O0), U10.58 (~WR)
~IRQ: Edge1.39 (~IRQ), JP9.1 (A)
~RES: Edge1.37 (~RES), U10.33 (~IC)
~ROMKIL: Edge1.29 (~ROMKIL), U5.11 (O5b)
~TMG2: Edge1.44 (~TMG2), JP6.1 (A)

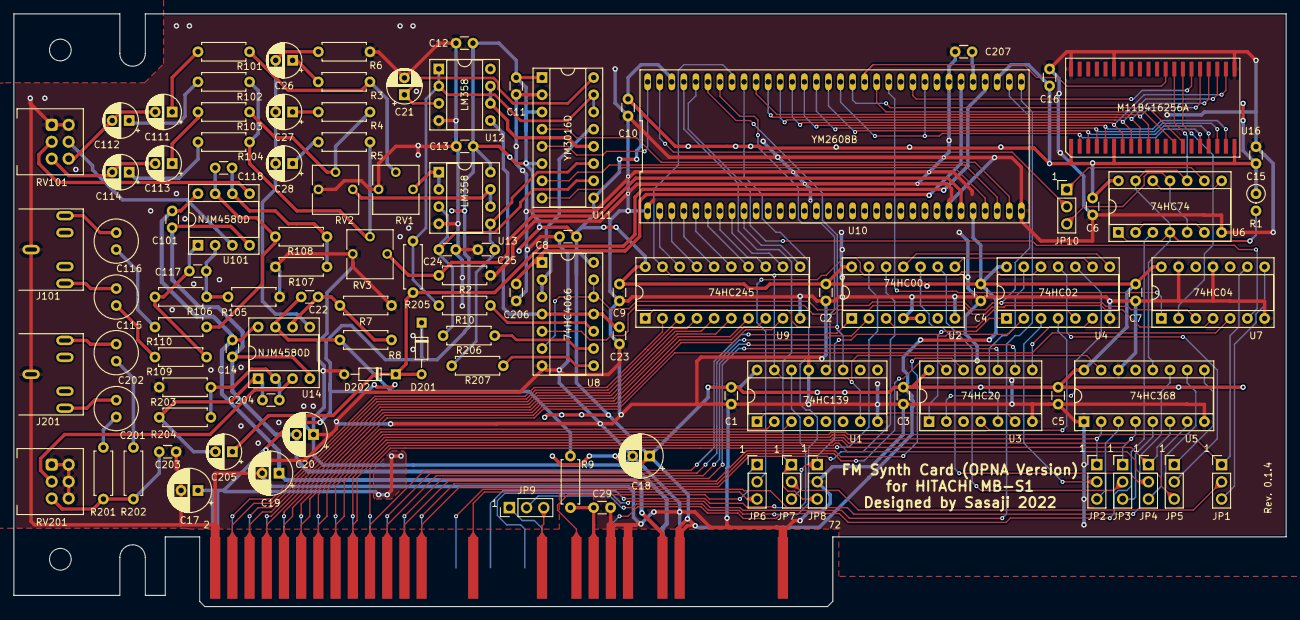
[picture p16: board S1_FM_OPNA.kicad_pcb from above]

Board: 2 copper layers, 187.8 x 87.5 mm, 108 parts (0 on the bottom side), 147 nets.
